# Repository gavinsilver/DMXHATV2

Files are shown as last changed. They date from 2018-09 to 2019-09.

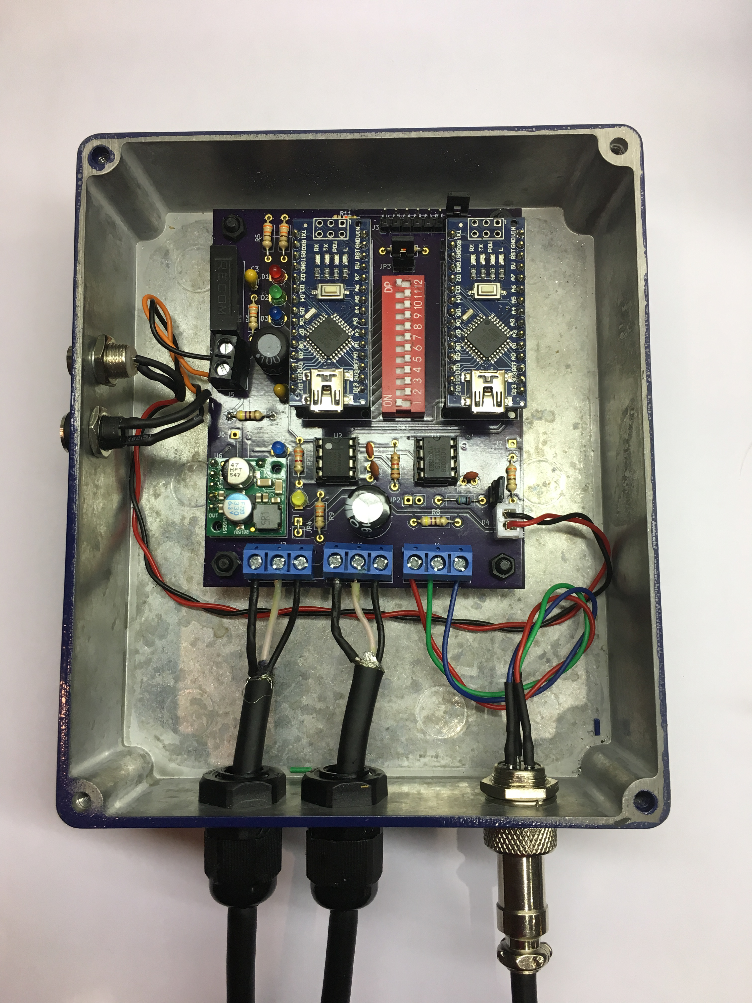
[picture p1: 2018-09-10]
PHOTOS/Board in case Sept 2018.jpg

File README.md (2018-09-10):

# DMXHATV2

DMX Interface to NeoPixel Strip

This is the first Alpha version of the board and software

Alpha Version of the board can be found at https://oshpark.com/shared_projects/N2rTY4Yk 

## DMX Interface to NeoPixel Strip

DMX to Neopixel board. Voltage Isolated DMX interface with separate Arduino Nano CPU’s for DMX and Neopixel driver

If you have tried driving NeoPixel strips from an Arduino and then tried to mix this with DMX then you 
may have hit the problem that the NeoPixel strip requires interrupts to be turned off when it is updated
and when this happens the DMX interface stops receiving data.  Even with small strips you may need to 
wait 50ms before the DMX data recovers.

This project is an attempt to get around this by have two Arduino Nano boards one dedicated to DMX
and the other to controlling the LED strip.  These subsystems communicate over an SPI interface.  The
DMX interface is also fully isolated which most of the cheaper DMX interfaces are not.

The PCB has been produced using KiCAD

The Arduino Code is written in the Arduino IDE

Gavin Silver - 8th June 2018

Copyright (c) Gavin Silver 2018, all rights reserved

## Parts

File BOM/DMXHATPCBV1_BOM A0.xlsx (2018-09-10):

 | Hat Project BOM
 | 3 | Boards Required |  |  |  |  |  | xx | = we have enough
Id | Designator | Package | Designation | Required per Board | Unit Cost | Cost Per Board | Order Units | Qty in Stock | On order | Required | Order | Supplier and ref
1 | U5,U3 | Arduino_Nano_WithMountingHoles | Nano | 2 | £3.00 | £5.99 | 3 | 7 |  | 6 |  | https://www.amazon.co.uk/gp/product/B072BMYZ18
2 | U1 | DIP-8_W7.62mm | CPC5002 | 1 | £2.05 | £2.05 |  | 16 |  | 3
3 | M3,M3,M3,M3 | MountingHole_3.2mm_M3 | M3 |  |  |  |  |  |  | 0 |  | no part required
4 | D1,D2,D3,D5 | LED_D3.0mm | LED | 4 |  | £0.00 |  | 12 |  | 12
5 | R8 | R_Axial_DIN0207_L6.3mm_D2.5mm_P10.16mm_Horizontal | 470 | 1 |  | £0.04 |  | 49 |  | 3
6 | C1 | C_Disc_D3.0mm_W1.6mm_P2.50mm | 10pF | 1 |  | £0.00 |  | 9 |  | 3
7 | C3,C4 | C_Disc_D3.0mm_W1.6mm_P2.50mm | 4.7uF | 2 |  | £0.20 |  | 8 |  | 6
8 | C5 | C_Disc_D3.0mm_W1.6mm_P2.50mm | 22pF | 1 |  | £0.00 |  | 9 |  | 3
9 | R1 | R_Axial_DIN0207_L6.3mm_D2.5mm_P10.16mm_Horizontal | 1.5K | 1 |  | £0.04 |  | 49 |  | 3
10 | R2 | R_Axial_DIN0207_L6.3mm_D2.5mm_P10.16mm_Horizontal | 3.3K | 1 |  | £0.00 |  | 48 |  | 3
11 | R3 | R_Axial_DIN0207_L6.3mm_D2.5mm_P10.16mm_Horizontal | 499 | 1 |  | £0.13 |  | 20 |  | 3
12 | R4,R5,R6,R9,R7 | R_Axial_DIN0207_L6.3mm_D2.5mm_P10.16mm_Horizontal | 330 | 5 |  | £0.00 |  | 40 |  | 15
13 | C2 | C_Disc_D3.0mm_W1.6mm_P2.50mm | 10nF | 1 |  | £0.00 |  | 9 |  | 3
14 | JP2,JP3,JP4 | Pin_Header_Straight_1x02_Pitch2.54mm | Jumper_NO | 3 |  | £0.00 |  | 9 |  | 9
15 | U2 | DIP-8_W7.62mm | MAX485 | 1 |  | £0.44 |  | 9 |  | 3
16 | D4 | Molex_KK-6410-02_02x2.54mm_Straight | LED | 1 |  | £0.00 |  | 3 |  | 3
17 | C7 | CP_Radial_D10.0mm_P5.00mm | 1000uF | 1 |  | £0.00 |  | 4 |  | 3
18 | SW1 | SW_DIP_x12_W7.62mm_Slide | SW_DIP_x12 | 1 |  | £0.42 |  | 4 |  | 3
19 | R10,R11 | R_Axial_DIN0207_L6.3mm_D2.5mm_P10.16mm_Horizontal | 10K | 2 |  | £0.04 |  | 48 |  | 6
20 | J5 | TerminalBlock_bornier-2_P5.08mm | 9V Input | 1 |  | £0.00 |  | 4 |  | 3
21 | J1,J2 | TerminalBlock_bornier-3_P5.08mm | DIN-3 & LED_Strip | 3 |  | £0.10 |  | 20 |  | 9
22 | J4 | TerminalBlock_bornier-3_P5.08mm | as above
23 | U4 | REE-0505S | REE-0505S | 1 |  | £3.08 |  | 0 | 3 | 3
24 | U6 | Pololu_D24V22Fx | Pololu_D24V22Fx | 1 | £6.72 | £6.72 |  | 1 | 2 | 3 |  | http://www.hobbytronics.co.uk/d24v22f5-5v-step-down-regulator?keyword=D24V22F5
25 | L1 | L1_Radial_D9.0mm | 10uH | 1 | £0.29 | £0.29 |  | 9 |  | 3
26 | J3 | Pin_Header_Straight_1x08_Pitch2.54mm | Conn_01x08 | 1 |  | £0.00 |  | 3 |  | 3
 |  | Other Components
 |  | PCB |  | 1 | £18.38 | £18.38 |  |  | 3 | 3
 |  | Cable Glands |  | 2 | £0.92 |  |  | 11 |  | 6
 |  | 3 Way DMX DIN Lead |  | 1 | £3.95 |  |  | 0 | 3 | 3 |  | Kenable?
 |  | 3 Way Aviation DIN Connector |  | 1 | £0.52 |  |  | 9 |  | 3
 |  | Hammond Box |  | 1 |  |  |  | 1 |  | 3 | 2 | RS ?
 |  | M3 Nylon Mounting Post |  | 4 |  |  |  | 30 |  | 12
 |  | M3 Screw |  | 4 |  |  |  | 30 |  | 12
 |  | M3 Nylon Nut |  | 4 |  |  |  | 30 |  | 12
 |  | Power LED gland |  | 1 |  |  |  | 3 |  | 3
 |  | Power LED 5mm RED |  | 1 |  |  |  | 3 |  | 3
 |  | Rubber Feet |  | 4 |  |  |  | 12 |  | 12
 |  | 2 Pin Header |  | 3 |  |  |  | 9 |  | 9
 |  | 2 Pin Jumper with grip |  | 3 |  |  |  | 0 | 10 | 9 |  | RS ?
 |  | 8 Pin Header |  | 1 |  |  |  | 3 |  | 3
 |  | DC Power Connector |  | 1 | £0.60 |  |  | 3 |  | 3
 |  | 3 PIN GX20 Aviation Plug |  |  | £5.70 |  |  | 2 |  | 0
 |  | 2 PIN GX20 Aviation Plug |  |  | £5.60 |  |  |  | 2 | 0
 |  | 8A PSU |  |  |  |  |  |  | 1 | 0
 |  |  |  |  | Total | £37.92
 | RS Order
 | Qty | Description | Part Number
 | 2 | Hammond Box
 | Keanbale Order
 | Qty | Description | Part Number
 | Ebay Order
 | Qty | Description | Part Number
 | Amazon Order
 | Qty | Description | Part Number
 | 2 | 8A 5V PSU

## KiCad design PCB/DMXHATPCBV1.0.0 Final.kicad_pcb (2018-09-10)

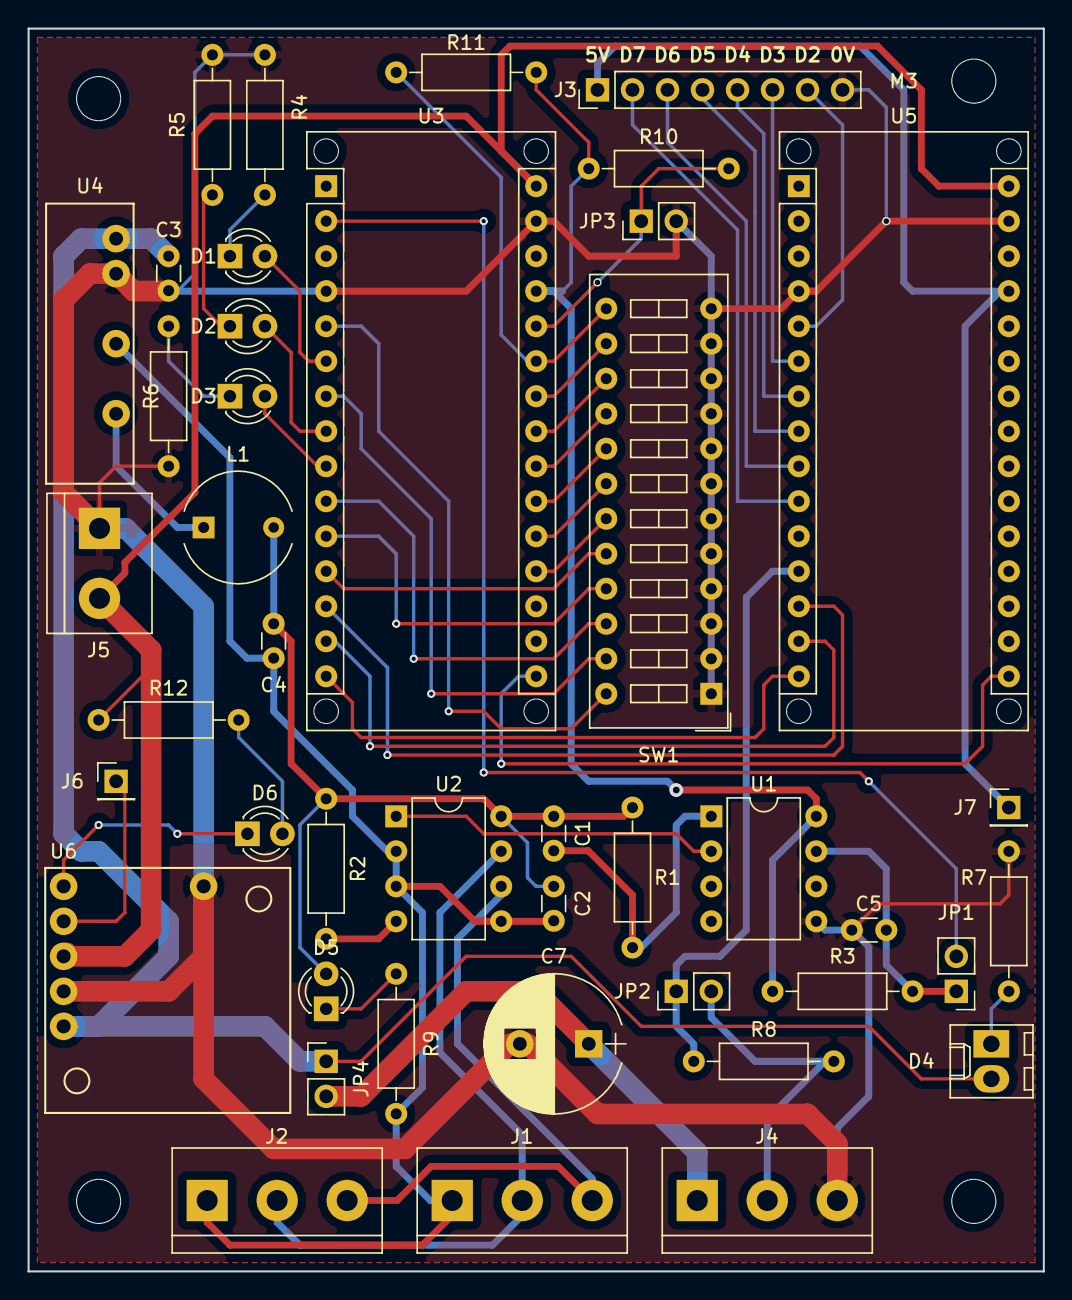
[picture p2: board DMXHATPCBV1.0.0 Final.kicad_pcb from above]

Board: 2 copper layers, 73.7 x 90.2 mm, 47 parts (0 on the bottom side), 52 nets.

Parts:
C1: 10pF; C_Disc_D3.0mm_W1.6mm_P2.50mm
C2: 10nF; C_Disc_D3.0mm_W1.6mm_P2.50mm
C3, C4: 4.7uF; C_Disc_D3.0mm_W1.6mm_P2.50mm
C5: 22pF; C_Disc_D3.0mm_W1.6mm_P2.50mm
C7: 1000uF; CP_Radial_D10.0mm_P5.00mm
D1, D2, D3, D5, D6: LED; LED_D3.0mm
D4: LED; Molex_KK-6410-02_02x2.54mm_Straight
J1: DMX In; TerminalBlock_bornier-3_P5.08mm
J2: DMX Out; TerminalBlock_bornier-3_P5.08mm
J3: D Outs; Pin_Header_Straight_1x08_Pitch2.54mm
J4: LED Strip; TerminalBlock_bornier-3_P5.08mm
J5: 9V Input; TerminalBlock_bornier-2_P5.08mm
J6: Power EN; Pin_Header_Straight_1x01_Pitch2.54mm
J7: 5V_U5; Pin_Header_Straight_1x01_Pitch2.54mm
JP1: Prog U3 NC; Pin_Header_Straight_1x02_Pitch2.54mm
JP2: R Bypass NO; Pin_Header_Straight_1x02_Pitch2.54mm
JP3: N/A NC; Pin_Header_Straight_1x02_Pitch2.54mm
JP4: Ext Power NC; Pin_Header_Straight_1x02_Pitch2.54mm
L1: 10uH; L1_Radial_D9.0mm
M3, M3#2, M3#3, M3#4: M3; MountingHole_3.2mm_M3
R1: 1.5K; R_Axial_DIN0207_L6.3mm_D2.5mm_P10.16mm_Horizontal
R2: 3.3K; R_Axial_DIN0207_L6.3mm_D2.5mm_P10.16mm_Horizontal
R3: 499; R_Axial_DIN0207_L6.3mm_D2.5mm_P10.16mm_Horizontal
R4, R5, R6, R7, R9: 330; R_Axial_DIN0207_L6.3mm_D2.5mm_P10.16mm_Horizontal
R8, R12: 470; R_Axial_DIN0207_L6.3mm_D2.5mm_P10.16mm_Horizontal
R10, R11: 10K; R_Axial_DIN0207_L6.3mm_D2.5mm_P10.16mm_Horizontal
SW1: SW_DIP_x12; SW_DIP_x12_W7.62mm_Slide
U1: CPC5002; DIP-8_W7.62mm
U2: MAX485; DIP-8_W7.62mm
U3, U5: Nano; Arduino_Nano_WithMountingHoles
U4: REE-0505S
U6: Pololu_D24V22Fx

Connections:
5V_2.5A: C3.1, D4.2, JP4.1, U4.1, U6.5
5V_U5: J3.1, J7.1, U5.27
5v: R3.1, R10.1, R11.1, U1.8, U3.27
9V: J5.2, R12.1, U3.30, U5.30, U6.3
+5V_ISO: C1.1, C2.1, C4.1, D5.2, L1.2, R1.1, R2.1, U2.8
GND: C3.2, C5.2, C7.2, J3.8, J4.3, J5.1, JP3.2, R4.2, R5.2, R6.2, R7.2, SW1.1, SW1.2, SW1.3, SW1.4, SW1.5, SW1.6, SW1.7, SW1.8, SW1.9, SW1.10, SW1.11, SW1.12, U1.5, U3.4, U3.29, U4.2, U5.4, U5.29, U6.4, U6.6
GND_ISO: C2.2, C4.2, J1.1, J2.1, R9.2, U2.2, U2.3, U2.5, U4.4
MISO: U3.15, U5.15
MOSI: U3.14, U5.14
unnamed: C1.2, R1.2, U1.1
unnamed: C5.1, JP1.1, R3.2, U1.7
unnamed: C7.1, J4.1, JP4.2
unnamed: D1.1, R4.1
unnamed: D1.2, U3.6
unnamed: D2.1, R5.1
unnamed: D2.2, U3.8
unnamed: D3.1, R6.1
unnamed: D3.2, U3.9
unnamed: D4.1, R7.1
unnamed: D5.1, R9.1
unnamed: D6.1, U6.1
unnamed: D6.2, R12.2
unnamed: J1.2, J2.2, U2.7
unnamed: J1.3, J2.3, U2.6
unnamed: J3.2, U5.10
unnamed: J3.3, U5.9
unnamed: J3.4, U5.8
unnamed: J3.5, U5.7
unnamed: J3.6, U5.6
unnamed: J3.7, U5.5
unnamed: J4.2, JP2.2, R8.2
unnamed: J6.1, U6.2
unnamed: JP1.2, U3.2
unnamed: JP2.1, R8.1, U5.12
unnamed: JP3.1, R10.2, U3.26
unnamed: L1.1, U4.6
unnamed: R2.2, U2.4
unnamed: R11.2, SW1.13, U3.25
unnamed: SW1.14, U3.24
unnamed: SW1.15, U3.23
unnamed: SW1.16, U3.22
unnamed: SW1.17, U3.21
unnamed: SW1.18, U3.20
unnamed: SW1.19, U3.19
unnamed: SW1.20, U3.12
unnamed: SW1.21, U3.11
unnamed: SW1.22, U3.10
unnamed: SW1.23, U3.7
unnamed: SW1.24, U3.5
unnamed: U1.2, U2.1
SCK: U3.16, U5.16
SS: U3.13, U5.13

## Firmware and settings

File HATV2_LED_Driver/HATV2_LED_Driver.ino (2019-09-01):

/*
 * HAT V2 Code to run on U5 CPU
 * 
 * Now on github.com/gavinsilver/DMXHATV2
 * 
 * 
 * HISTORY
 * 
 * V2.0   Initail Version 
 * V2.1   Added Strand test overide mode when Pin D3 is high
 */
#define VER_ID "2.2"
// SPI Library
#include <SPI.h>

// Neopixel Library



#include <Adafruit_NeoPixel.h>
#ifdef __AVR__
  #include <avr/power.h>
#endif

#define PIN 9
#define NUM_LEDS 50 // Maximum a 2A 9V Power Supply can deliver all LEDs on White

// Parameter 1 = number of pixels in strip
// Parameter 2 = Arduino pin number (most are valid)
// Parameter 3 = pixel type flags, add together as needed:
//   NEO_KHZ800  800 KHz bitstream (most NeoPixel products w/WS2812 LEDs)
//   NEO_KHZ400  400 KHz (classic 'v1' (not v2) FLORA pixels, WS2811 drivers)
//   NEO_GRB     Pixels are wired for GRB bitstream (most NeoPixel products)
//   NEO_RGB     Pixels are wired for RGB bitstream (v1 FLORA pixels, not v2)
//   NEO_RGBW    Pixels are wired for RGBW bitstream (NeoPixel RGBW products)

Adafruit_NeoPixel strip = Adafruit_NeoPixel(NUM_LEDS, PIN, NEO_GRB + NEO_KHZ800);

// IMPORTANT: To reduce NeoPixel burnout risk, add 1000 uF capacitor across
// pixel power leads, add 300 - 500 Ohm resistor on first pixel's data input
// and minimize distance between Arduino and first pixel.  Avoid connecting
// on a live circuit...if you must, connect GND first.

/// setup global variables for main code segment.

const int debugPin = 2; // Set debug Pin when held low we go into debug mode
const int strandTestPin = 3; // If Pin is High then just ignore DMX and just run the strand test
const int ledPin = 7;   // debug  LED pin
boolean debugon=false;  // debug Mode
boolean strandteston=false; //sstrand test mode

//long unsigned int time_debug = 2; // ms delay between strobes to turn on LED

long unsigned int millis_now =0;              // hold current millis value for this loop
long unsigned int DMX_read_interval = 3;     // interval in ms between reading DMX values 
long unsigned int DMX_last_check_millis = 0;  // value of millis last time we checked the DMX values 

     

byte redVal = 0;        // red value 0-255 (Channel 1)
byte dim_red = 0;       // after dimer value is applied
byte red_last =0;       // holds the laste value when checking the DMX to see if it has changed

byte greenVal = 0;      // green value 0-255 (Channel 2)
byte dim_green = 0;
byte green_last = 0;

byte blueVal = 0;       // blue value 0-255 (Channel 3)
byte dim_blue = 0;
byte blue_last = 0;

byte dim_val = 0;       // dimmer value 0 (off) to 255 (full) (Channel 4)
byte dim_val_last = 0;

byte strobe_val = 0;    // 000 - Solid On
                        // 001 - 50ms Strobe
                        // 002 - 254 - Linear between 50ms and 500ms
                        // 255 - 500ms Strobe
int strobe_val_last = 0;
long unsigned int strobe_ms = 30;                // Strobe transition time in Ms
const int strobe_min = 30;       // Minimum Strobe Transition in Ms
const int strobe_max = 500;     // Maximun Strobe Transition in Ms
boolean strobe_on = false;      // True if Strobe should be on
boolean strobe_change = false;  // True if Strobe state has changed
long unsigned int strobe_last_transition_millis; // what the millis function returned last time we changed strobe state

void setup() {

  strip.begin();
  strip.show(); // Initialize all pixels to 'off'

  // start serial port for debug
  // if debug enabled
  Serial.begin(115200);
  Serial.println("Starting ....");
  Serial.print("HATV2_LED Ver : ");  
  Serial.println(VER_ID);  
    
  // Setup Debug Pin (D2) if D2 is held low then debug mode is enabled
  pinMode (ledPin, OUTPUT);
  pinMode(debugPin, INPUT_PULLUP);
  pinMode(strandTestPin, INPUT_PULLUP);
  if (digitalRead(debugPin) == LOW) // see if we are in debug mode
    {
    debugon = true; // we are in debug Mode
    Serial.println("Debug is ON");
    Serial.println("LED test");
    // Startup Colour Test (in Debug Mode)
    colorWipe(strip.Color(255, 0, 0), 100); // Red
    colorWipe(strip.Color(0, 255, 0), 100); // Green
    colorWipe(strip.Color(0, 0, 255), 100); // Blue
    colorWipe(strip.Color(255, 255, 255), 100); // White
    colorWipe(strip.Color(0, 0, 0), 100);   // Off
    
    }
  else
    {
      Serial.println("Debug is OFF");
    }
  if (digitalRead(strandTestPin) == LOW) // see if we are in strand test mode
    {
    strandteston = true; // we are in strand test only mode
    Serial.println("Strandtest Mode is ON");
    }
  // Setup the SPI Interface
  digitalWrite(SS, HIGH);  // ensure SS stays high for now
  // Put SCK, MOSI, SS pins into output mode
  // also put SCK, MOSI into LOW state, and SS into HIGH state.
  // Slow down the master a bit
  SPI.setClockDivider(SPI_CLOCK_DIV8);
  // Then put SPI hardware into Master mode and turn SPI on
  SPI.begin ();
}

void loop() {

  if (strandteston == true) { // if we are in strandtest mode we are only doing a strandtest
    
    while (true) {             // do this FOREVER (DMX is ignored)
      rainbow(30);             // Flowing rainbow cycle along the whole strip with 30ms 
    }
  }
  
  if (digitalRead(debugPin) == LOW) // see if we are in debug mode
    {
      debugon = true; // we are in debug Mode
      Serial.println("Debug is ON");
    }
  else
    {
      debugon = false; // we are in debug Mode
      //Serial.println("Debug is OFF");
    }
  millis_now = millis();              // read current millis for this loop
  if (debugon) {
    Serial.print("Loop Milis_now = ");
    Serial.println(millis_now);
  }

  // see if we need to change strobe state
  // to do - add handelingin for millis wrap (after 9 hrs)
  if (strobe_val !=0) {
      if ((millis_now - strobe_last_transition_millis) > strobe_ms) {
        // code to change strobe state
        if (strobe_on) {
          strobe_on = false;
          colorWipe(strip.Color(0, 0, 0), 0); // turn everything off
          strobe_last_transition_millis = millis_now;
        }
        else {
          strobe_on = true;
          colorWipe(strip.Color(dim_red, dim_green, dim_blue), 0); // turn everything back as it was
          strobe_last_transition_millis = millis_now;
        }
      }
  }
  
  else {
    // Code to force to turn off strobe.  This is to handle the case where the strobe goes from on to off.
    if (strobe_on) {
      strobe_on = false;      // Turn Strobe off
      strobe_change = false;  // we dont need to change
      // write data to LED strip
      colorWipe(strip.Color(dim_red, dim_green, dim_blue), 0); // make sure pixels are set to original values, no wipe.
    }  
  }
 
  if ((millis_now - DMX_last_check_millis) > DMX_read_interval) { //section reading DMX Values
        
    // Read the current values from the DMX CPU using SPI Interface
    if (debugon) {
      Serial.println("Read DMX over SPI");
    }
    // enable Slave Select
    digitalWrite(SS, LOW);
    
    transferAndWait(1);
    redVal = transferAndWait(2);
    greenVal = transferAndWait(3);
    blueVal = transferAndWait(4);
    dim_val = transferAndWait(5);
    strobe_val = transferAndWait(0);
    DMX_last_check_millis = millis_now; // record the last time we read the DMX interface
    digitalWrite(SS, HIGH);

    if (debugon) {
      Serial.print("Red Value =");
      Serial.println(redVal);
      Serial.print("Green Value =");
      Serial.println(greenVal);
      Serial.print("Blue Value =");
      Serial.println(blueVal);
      Serial.print("Dim Value =");
      Serial.println(dim_val);
      Serial.print("Strobe Value =");
      Serial.println(strobe_val);
      Serial.println("");
      delay(100);
    }
      
    // see if any DMX channel values have changed?
    if ((redVal != red_last) || (greenVal != green_last) || (blueVal != blue_last)|| (dim_val != dim_val_last) || (strobe_val != strobe_val_last)){
      // now calculate the dimmed value of RGB
      digitalWrite(ledPin, HIGH);  // debug
      dim_red = newmap(redVal, 0, 255, 0, dim_val); 
      dim_green = newmap(greenVal, 0, 255, 0, dim_val);
      dim_blue = newmap(blueVal, 0, 255, 0, dim_val);
  
      // now look at the Strobe value to see if it has changed
      if (strobe_val != strobe_val_last){
        // Strobe Value has changed
        if ((strobe_val == 0) ){  // Always On, i.e. no strobe efect
          // Settings for solid on;
          strobe_ms = strobe_max;
          strobe_on = false;
        }
        else {  // We are strobing
          // Calculating strobe timing
          strobe_ms = newmap(strobe_val, 1, 255, strobe_max, strobe_min); // Calculate strobe value in Ms where 
          // 0=off 1 = 500ms up to 255 = 50ms
        }
      }
      // write data to LED strip when a DMX valuse has changed (should we ignore changes to strobe?)
      colorWipe(strip.Color((int)dim_red, dim_green, dim_blue), 0); // something has changed so change pixels, no wipe.
  
      // Record previous DMX RGB, Dim & Strobe values
      red_last = redVal;
      green_last = greenVal;
      blue_last = blueVal;
      dim_val_last = dim_val;
      strobe_val_last = strobe_val;
    }
   
  }  // end of section reading DMX Values
   
} // end of void loop()

// FUNCTIONS

// Neopixel Strip, fill the dots one after the other with a color
void colorWipe(uint32_t c, uint8_t wait) {
  for(uint16_t i=0; i<strip.numPixels(); i++) {
    strip.setPixelColor(i, c);
    strip.show();
    delay(wait);
  }
}

// SPI Transfer & Wait return the Byte
byte transferAndWait (const byte what)
{
  byte a = SPI.transfer (what);
  delayMicroseconds (40);  // Wait 40 Microseconds to stop ocassional mis reads at 20 Microseconds
  return a;
} // end of transferAndWait

// New Map command supposed to give a smoother range (from http://forum.arduino.cc/index.php?topic=417690.30 )
long newmap(long x, long in_min, long in_max, long out_min, long out_max)
{
  if( x == in_max)
    return out_max;
  else if(out_min < out_max)
    return (x - in_min) * (out_max - out_min+1) / (in_max - in_min) + out_min;
  else
    return (x - in_min) * (out_max - out_min-1) / (in_max - in_min) + out_min;
}

// 

// Rainbow cycle along whole strip. Pass delay time (in ms) between frames.
void rainbow(int wait) {
  // Hue of first pixel runs 5 complete loops through the color wheel.
  // Color wheel has a range of 65536 but it's OK if we roll over, so
  // just count from 0 to 5*65536. Adding 256 to firstPixelHue each time
  // means we'll make 5*65536/256 = 1280 passes through this outer loop:
  for(long firstPixelHue = 0; firstPixelHue < 5*65536; firstPixelHue += 256) {
    for(int i=0; i<strip.numPixels(); i++) { // For each pixel in strip...
      // Offset pixel hue by an amount to make one full revolution of the
      // color wheel (range of 65536) along the length of the strip
      // (strip.numPixels() steps):
      int pixelHue = firstPixelHue + (i * 65536L / strip.numPixels());
      // strip.ColorHSV() can take 1 or 3 arguments: a hue (0 to 65535) or
      // optionally add saturation and value (brightness) (each 0 to 255).
      // Here we're using just the single-argument hue variant. The result
      // is passed through strip.gamma32() to provide 'truer' colors
      // before assigning to each pixel:
      strip.setPixelColor(i, strip.gamma32(strip.ColorHSV(pixelHue)));
    }
    strip.show(); // Update strip with new contents
    delay(wait);  // Pause for a moment
  }
}

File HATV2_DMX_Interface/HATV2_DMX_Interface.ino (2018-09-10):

/*
 * DMX Interface Code - Runs on the DMX Nano CPU U5 on board
 * 
 * Now on github.com/gavinsilver/DMXHATV2
 * 
 * V1.0 - First Version
 * V1.1 - Added Debug and fake DMX for testing
 */

#include <Conceptinetics.h>

//
// The slave device will use a block of 10 channels counting from
// its start address.
//
// If the start address is for example 56, then the channels kept
// by the dmx_slave object is channel 56-66
//
#define DMX_SLAVE_CHANNELS  5 

// Configure a DMX slave controller
DMX_Slave dmx_slave ( DMX_SLAVE_CHANNELS );

#define DEBUG_PIN A7    // Set debug Pin when held low we go into debug mode
#define FAKE_DMX A6     // Set Pin to use to swith on fake DMX
boolean debugon=false;  // debug Mode
boolean fakedmx=false;  // create fake DMX data for testing 
int fakedmxi=0;         // counter used to cycle through colours

const int ledPinRed = 3;
const int ledPinGreen = 5;
const int ledPinBlue = 6;
volatile byte redVal = 0;
volatile byte greenVal = 0;
volatile byte blueVal = 0;
volatile byte dimVal = 0;
volatile byte strobeVal = 0;

int dmx_add = 0;  // 0 - 511
int dmx_mode = 0; // 0-7
int val = 0;      // Temp variable used to read input

volatile byte DMXval = 0;

// the setup routine runs once when you press reset:
void setup() {    

  // SPI Setup have to send on master in, *slave out*
  pinMode(MISO, OUTPUT);

  // turn on SPI in slave mode
  SPCR |= _BV(SPE);

  // turn on interrupts
  SPCR |= _BV(SPIE);
   
  // Setup pins to read DMX address and DMX_Mode.  Becuse of the internal pullup resistor 
  // when the swith id off the input will be HIGH and when the switch is on the input will
  // be LOW
  // read in DMX address (9bits)
  
  pinMode(2, INPUT_PULLUP);
  pinMode(4, INPUT_PULLUP);
  pinMode(7, INPUT_PULLUP);
  pinMode(8, INPUT_PULLUP);
  pinMode(9, INPUT_PULLUP);
  pinMode(A0, INPUT_PULLUP);
  pinMode(A1, INPUT_PULLUP);
  pinMode(A2, INPUT_PULLUP);
  pinMode(A3, INPUT_PULLUP);
  pinMode(A4, INPUT_PULLUP);
  pinMode(A5, INPUT_PULLUP);
  pinMode(A6, INPUT); // Note A6 & A7 Analog only and need external pullup resistor
  pinMode(A7, INPUT); // Also can only be read with AnalogRead!

  // read in DMX address (9bits)
  dmx_add = 0;
  val = digitalRead(2); 
  if (val==LOW) {
      dmx_add |= 1;
    };
  val = digitalRead(4); 
  if (val==LOW) {
      dmx_add |= 1<<1;
    };
  val = digitalRead(7); 
  if (val==LOW) {
      dmx_add |= 1<<2;
    };
  val = digitalRead(8); 
  if (val==LOW) {
      dmx_add |= 1<<3;
    };
  val = digitalRead(9); 
  if (val==LOW) {
      dmx_add |= 1<<4;
    };
  val = digitalRead(A0); 
  if (val==LOW) {
      dmx_add |= 1<<5;
    };
  val = digitalRead(A1); 
  if (val==LOW) {
      dmx_add |= 1<<6;
    };
  val = digitalRead(A2); 
  if (val==LOW) {
      dmx_add |= 1<<7;
    };
  val = digitalRead(A3); 
  if (val==LOW) {
      dmx_add |= 1<<8;
    };

    // Read debug Mode
  val = analogRead(A7); 
  if (val<500) {
      debugon = true;
    }
    else {
      debugon = false;
    }
  
  // Read fake DMX Mode
  val = analogRead(A6); 
  if (val<=500) {
      fakedmx = true;
    }
    else {
      fakedmx = false;
    }
    
  // Enable DMX slave interface and start recording
  // DMX data
  dmx_slave.enable ();  
  
  // Set start address to 1, this is also the default setting
  // You can change this address at any time during the program
  dmx_slave.setStartAddress (dmx_add);
  
  // Set led pin as output pin
  pinMode ( ledPinRed, OUTPUT );
  pinMode ( ledPinGreen, OUTPUT );
  pinMode ( ledPinBlue, OUTPUT );

  // light up LED's if we are in Debug Mode
  if (debugon == true) {
      // turn on each RGB led on one at a time to test if we are in debug mode
      analogWrite(ledPinRed,255);
      delay(500);
      analogWrite(ledPinGreen,255);
      delay(500);
      analogWrite(ledPinBlue,255);
      delay(500);
      // now turn off all the leds,
      analogWrite(ledPinRed,0);
      analogWrite(ledPinGreen,0);
      analogWrite(ledPinBlue,0);
  }
}

// SPI interrupt routine
ISR (SPI_STC_vect)
{
  byte c = SPDR;
  if (c == 1) {
    SPDR = redVal;
  }
  if (c == 2) {
    SPDR = greenVal;
  }
  if (c == 3) {
    SPDR = blueVal;
  }
  if (c == 4) {
    SPDR = dimVal;
  }
  if (c == 5) {
    SPDR = strobeVal;
  }

}  // end of interrupt service routine (ISR) SPI_STC_vect

// the loop routine runs over and over again forever:
void loop() 
{
  //
  // EXAMPLE DESCRIPTION
  //

  if (fakedmx == true){
    // Fake the DMX output to Flashing Light Pink
    fakedmxi++;
    if (fakedmxi >= 101) fakedmxi=0; // reset back to start of sequence
    if (fakedmxi <= 25) {
      // RED
      redVal = 255;
      greenVal = 0;
      blueVal = 0;
      dimVal = 255;
      strobeVal = 0;
    }
    if ((fakedmxi > 25) and (fakedmxi <= 50 )) {
      // GREEN
      redVal = 0;
      greenVal = 255;
      blueVal = 0;
      dimVal = 255;
      strobeVal = 0;
    }
    if ((fakedmxi > 50) and (fakedmxi <= 75 )) {
      // BLUE
      redVal = 0;
      greenVal = 0;
      blueVal = 255;
      dimVal = 255;
      strobeVal = 0;
    }
    if ((fakedmxi > 75) and (fakedmxi <= 100 )) {
      // WHITE
      redVal = 255;
      greenVal = 255;
      blueVal = 255;
      dimVal = 255;
      strobeVal = 0;
    }
  }
  else {
    // Read the data from the DMX Interface
    // Uses PWM on 3 pins to do RGB in a very crude way.
    // NOTE:
    // getChannelValue is relative to the configured startaddress
    redVal = dmx_slave.getChannelValue(1);
    analogWrite(ledPinRed,redVal);
    greenVal = dmx_slave.getChannelValue(2);
    analogWrite(ledPinGreen,greenVal);
    blueVal = dmx_slave.getChannelValue(3);
    analogWrite(ledPinBlue,blueVal);
    dimVal = dmx_slave.getChannelValue(4);
    strobeVal = dmx_slave.getChannelValue(5); 
  }

  delay(20);
  
}

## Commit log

2018-06-08 PCB Added
    This is the final version of the Alpha1 PCB sent to OSH Park for fabrication
    [DMXHATPCBV1.0.0 Final.kicad_pcb]
2018-09-10 1st Board Test Version
    Changed LED's to 50
    Removed some debug code
    Change SPI Delay to 40 Micrososconds to stop occasional SPI data read corruptions
2018-09-10 1st Board Test Version
    Added function to Fake DMX data using pin 12 Colour cycles RGBW ever 25 cycles through Void Loop ()
    Fixed issue with pins A6 & A7 not working with digital reads
    [HATV2_DMX_Interface.ino]
2018-09-10 Bill of Materials Added
    Bill of Materials in Excel format required to build board
    [DMXHATPCBV1_BOM A0.xlsx]
2018-09-10 Board in Case
    Pcture of the board assemebeled in the case
